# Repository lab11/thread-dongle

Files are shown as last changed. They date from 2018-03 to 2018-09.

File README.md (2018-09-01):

Thread USB Dongle
=================

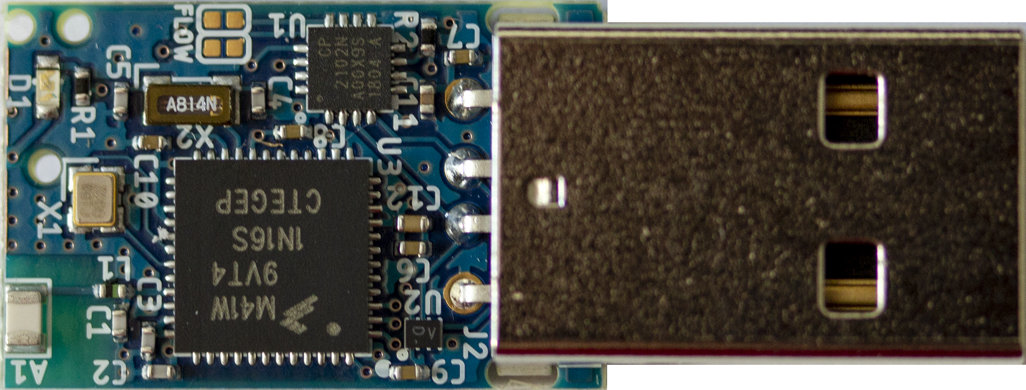
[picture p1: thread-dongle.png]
Thread Dongle


This repo holds the designs for an IEEE 802.15.4 USB dongle that is compatible
with the thread networking stack and supported by [Openthread](https://github.com/openthread/openthread).
The dongle functions as an NCP mode and is compatible with the OpenThread
[Border Router](https://github.com/openthread/borderrouter).

Currently there are no readily available commercial IEEE USB Thread NCP dongles
for a reasonable cost. This dongle is designed to be inexpensive, consists of
only a USB connector, serial to UART converter, and an 802.15.4 radio SoC.

Hardware designs are located in
[hardware](https://github.com/lab11/thread-dongle/tree/master/hardware), and
firmware is located in
[software](https://github.com/lab11/thread-dongle/tree/master/software).
Firmware is based on the OpenThread NCP implementation.

To clone this repo and submodules:
```
git clone --recursive https://github.com/lab11/thread-dongle.git
```

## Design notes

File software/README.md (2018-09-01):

Thread USB Dongle Firmware
==========================

Ensure the OpenThread submodule is initialized and checked out:
```
git submodule init
git submodule update
```

Install required dependencies and build the NCP firmware:
```
./build
```

Flash the firmware with a SEGGER jlink probe:
```
./flash
```

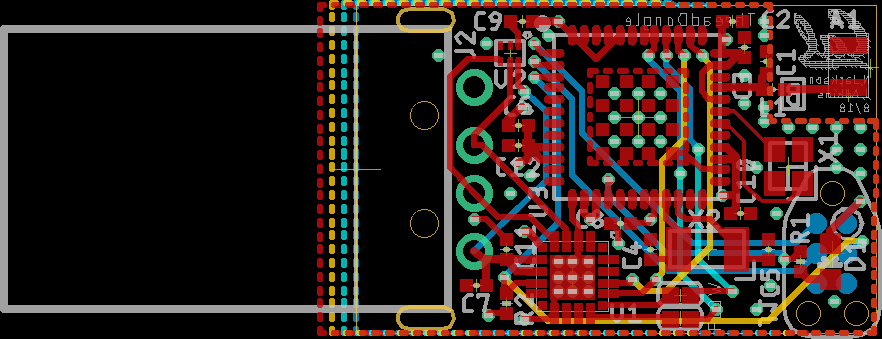
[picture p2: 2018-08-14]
hardware/rev_b/thread_dongle_pcb.png

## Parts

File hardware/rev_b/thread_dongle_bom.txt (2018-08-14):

# Bill of Materials
# Converted from thread_dongle_bom.xlsx
# Generated by bom_to_text.py
#
# # Bill of Materials                                                                                                                                                                                                   
# # Converted from {}                                                                                                                                                                                                   
# # Generated by bom_to_text.py                                                                                                                                                                                         
# #                                                                                                                                                                                                                     
#                                                                                                                                                                                                                       
# thread_dongle                                                                                                                                                                                                         
# Qty                            Value            Device             Package                     Parts                Description                          DIGIKEY                MANUFACTURER  MPN                     Notes
1                                                 AH212M             AH212M                      A1                   Small 2.4Ghz chip antenna            587-2725-1-ND                        AH212M245001-T          
1                                                 INDUCTOR0402       0402_CAP                    L1                   A very specific inductor             490-6573-1-ND                        LQG15HS5N1S02D          
5                                0.1uF            CAPACITOR0402_CAP  0402_CAP                    C6, C7, C8, C9, C10  SMD Capacitor                        587-1227-1-ND                        LMK105BJ104KV-F         Substitute OK
1                                0.7pF            CAPACITOR0402_CAP  0402_CAP                    C1                   SMD Capacitor                        490-6267-1-ND                        GRM1555C1HR70BA01D      Substitute OK
1                                1.0uF            CAPACITOR0402_CAP  0402_CAP                    C11                  SMD Capacitor                        490-10018-1-ND                       GRM155R61E105MA12D      Substitute OK
1                                10k              RESISTOR0402_RES   0402_RES                    R2                   Resistor                             311-10KJRCT-ND                       RC0402JR-0710KL         Substitute OK
4                                12pF             CAPACITOR0402_CAP  0402_CAP                    C2, C3, C4, C5       SMD Capacitor                        490-5924-1-ND                        GRM1555C1H120JA01D      Substitute OK
1                                1k               RESISTOR0402_RES   0402_RES                    R1                   Resistor                             311-1.0KJRCT-ND                      RC0402JR-071KL          Substitute OK
1                                4.7uF            CAPACITOR0402_CAP  0402_CAP                    C12                  SMD Capacitor                        490-5915-1-ND                        GRM155R60J475ME47D      Substitute OK
1                                CP2102N-20       CP2102N-20         QFN-20-3MM                  U1                   A cheap, simple USB to UART adapter  336-3692-ND            SiLabs        CP2102N-A01-GQFN20      
1                                ESDR0502N        ESDR0502N          UDFN-6                      U2                                                        ESDR0502NMUTBGOSCT-ND                ESDR0502NMUTBG          
1                                FA-128           FA-128             FA-128                      X1                   Epson MHz RANGE CRYSTAL UNIT         SER4079CT-ND                         FA-128 32.0000MF20X-K5  
1                                FA-135           FA-135             FC-135                      X2                   Epson kHz RANGE CRYSTAL UNIT         SER4086CT-ND                         FC-135 32.7680KA-AG3    
1                                KW41Z            KW41Z              LAMINATE-QFN-48-7MM         U3                   NXP KW21Z Cortex M0+ 802.15.4        MKW41Z512VHT4-ND                     MKW41Z512VHT4           
1                                LED0603          LED0603            LED-0603                    D1                   LED                                  160-1837-6-ND                        LTST-C194TBKT           
1                                USB-A-MALE-PLUG  USB-A-MALE-PLUG    USB_A_MALE_PLUG_CUI_UP2-AH  J2                   USB A Male plug connector            102-3996-ND            CUI           UP2-AH-1-TH

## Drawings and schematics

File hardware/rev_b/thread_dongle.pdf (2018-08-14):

1 FLOWCONTROL ENABLE | C10, C11, C12 place close to pin 20, 44, 28 C13, C14 place close to pins 36, 35 USB-A-MALE-PLUG | 3v3 GND | GND U² ESDR⁰⁵⁰²N | 0.1uF 4.7uF 0.1uF 1.0uF | GND GND GND | TC2030-JLINK-NL ³v3 GND ¹⁰k | LED⁰⁶⁰³ ³v3 | 1k CP2102N-20 | 0.1uF | 0.1uF | 0.1uF 12pF | 12pF | GND ³v3 GND | FA-128 FA-135 GND | 0.7pF GND ¹²pF | 12pF GND ⁺⁵V | P$1 D- | P$2 D+ | P$3 GND | P$4 J2 | VUSB P$6 D⁺ P$5 D⁻ P$4 GND P$1 | C⁶ C¹² C⁷ C¹¹ | SWDIO SWDCLK SWO RESET | VCC GNDJ1 R² | D¹ R¹ GND D- D+VBUS VREGIN | RST TXD RXD CTS RTS GPIO0/CLK GPIO1/485 WAKEUP SUSPEND SUSPEND VDD GPIO2/TXT GPIO3/RXT U1 | SWD_DIO 1 | SWD_CLK 2 | RESET 3 | PTA16 | 4 PTA17 | 5 PTA18 | 6 PTA19 | 7 PSWITCH 8 | DCDC_CFG 9 | DCDC_LP 11 | DCDC_LN 12 | VDD_1P8_OUT 14 | PTB0 | 16 PTB1 | 17 PTB2 | 18 PTB3 | 19 VDD 10*4 | PTB16/EXTAL32K 21 | PTB17/XTAL32K 22 | PTB18 | 23 ADC0_DP0 | 24 ADC0_DM0 | 25 VREFH | 27 VDDA 28 | XTAL_OUT 29 | EXTAL 30 | XTAL 31 | ANT | 33 VDD_RF 35*2 | PTC1 | 37 PTC2 | 38 PTC3 | 39 PTC4 | 40 PTC5 | 41 PTC6 | 42 PTC7 | 43 PTC17 | 46 PTC18 | 47 PTC19 | 48 GND 13*19 | VDD_1P5/PMC 15 | PTC16 | 45 U3 KW41Z C⁸ | C⁹ | C¹⁰ C² | C³ 1 | 3 X1GND 2 | 1 X2 | L1 C¹ SJ1 SJ2 | C⁴ | C⁵ | RESET RESET RESET | SWDIO | SWDIO CP_RTS CP_RTS | KW21Z_RX KW21Z_RX | KW21Z_TX KW21Z_TX | KW21Z_CTS KW21Z_CTS | KW21Z_RTS KW21Z_RTS | CP_CTS CP_CTS | SWDCLK SWDCLK

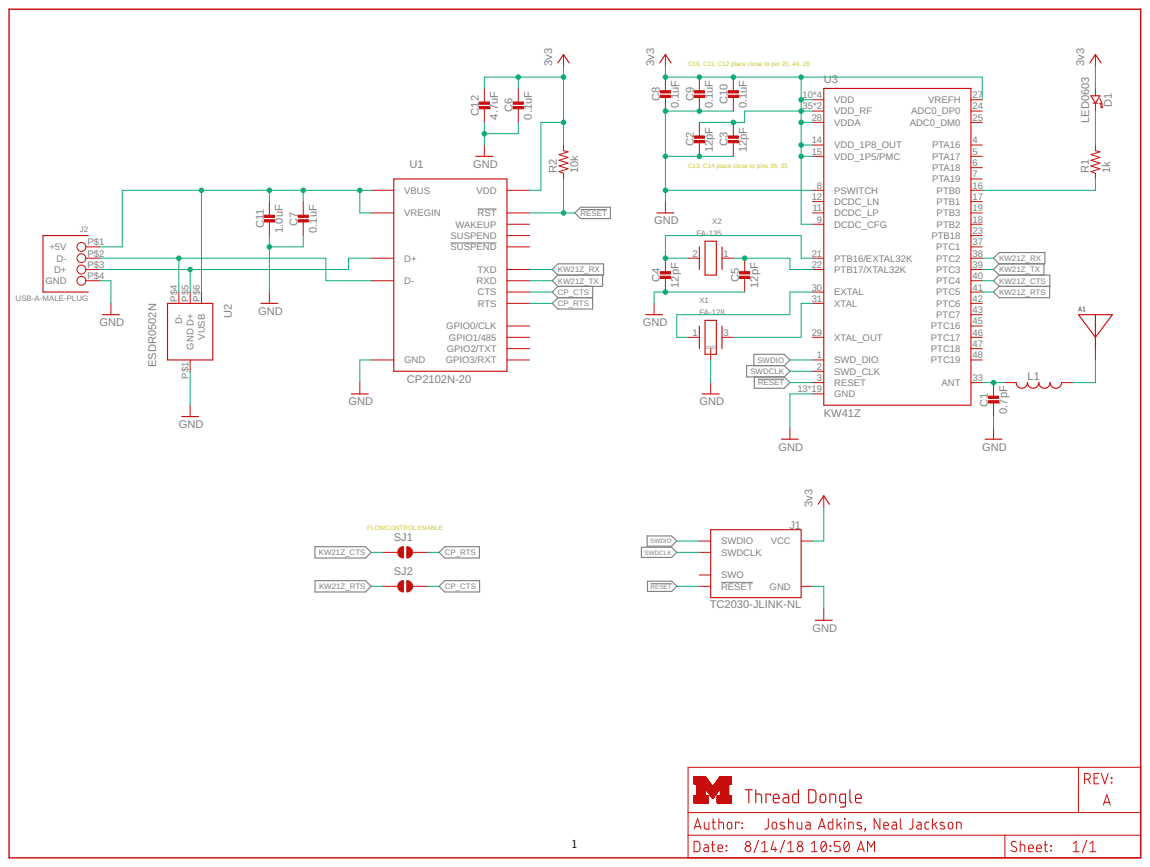
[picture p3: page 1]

## Top and Bottom Layers

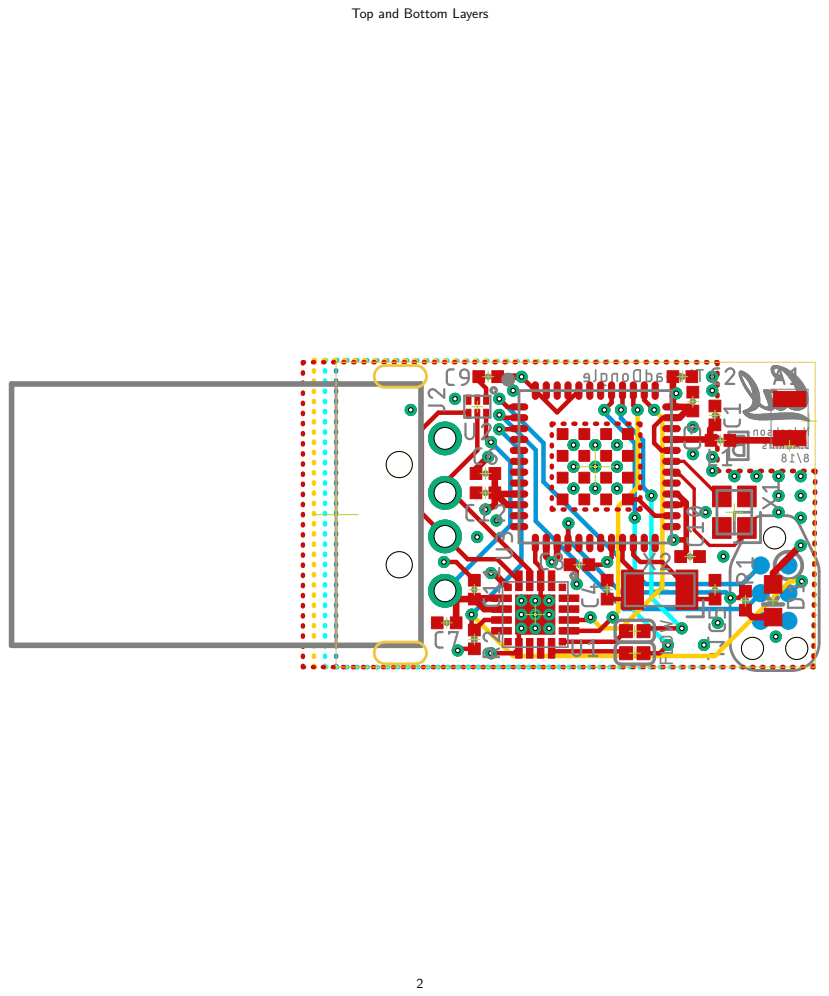
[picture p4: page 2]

## Top Layer

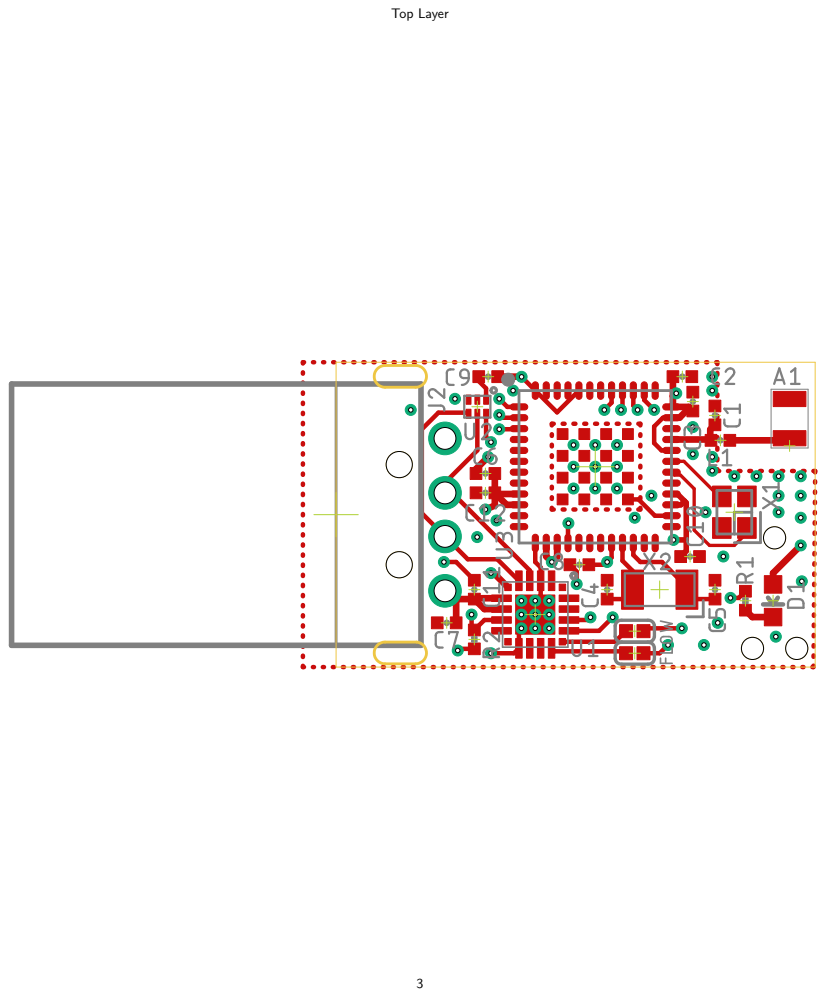
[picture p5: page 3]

## Bottom Layer

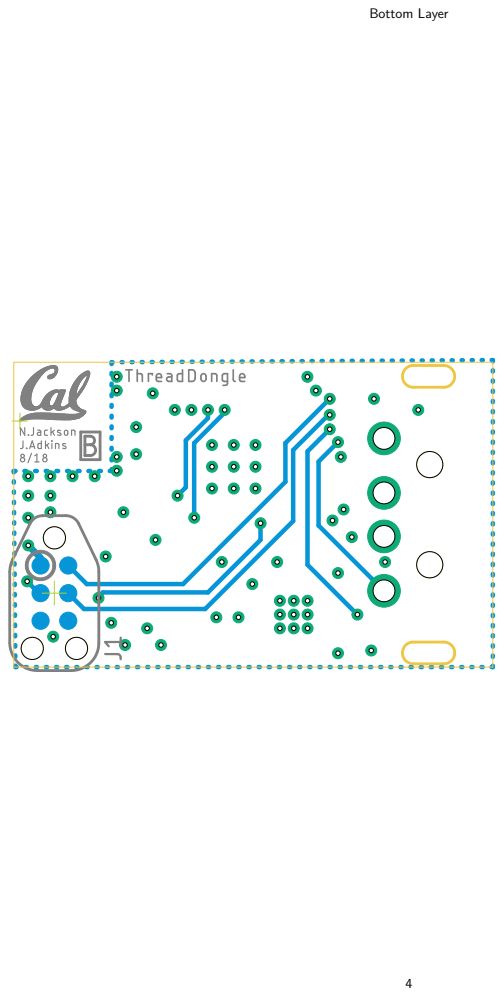
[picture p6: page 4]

## Top Copper Layer

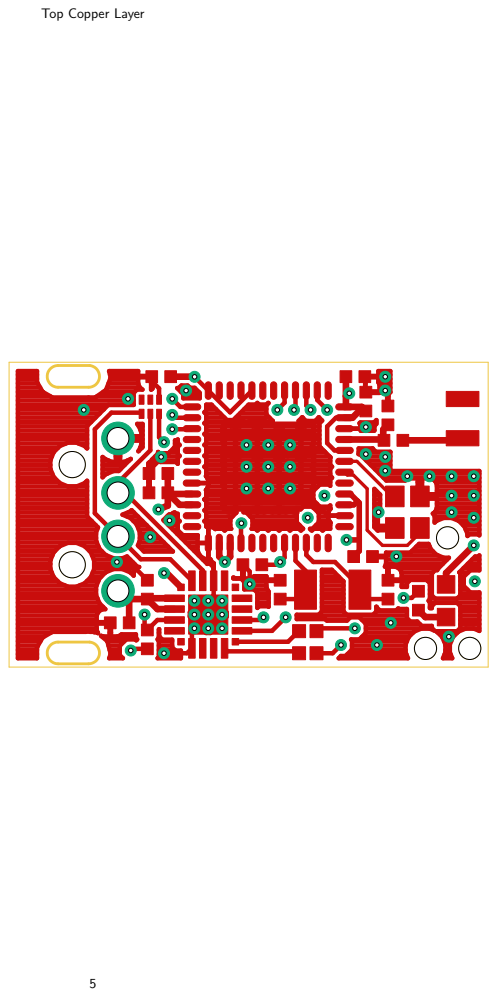
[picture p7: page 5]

## Layer 2 Copper

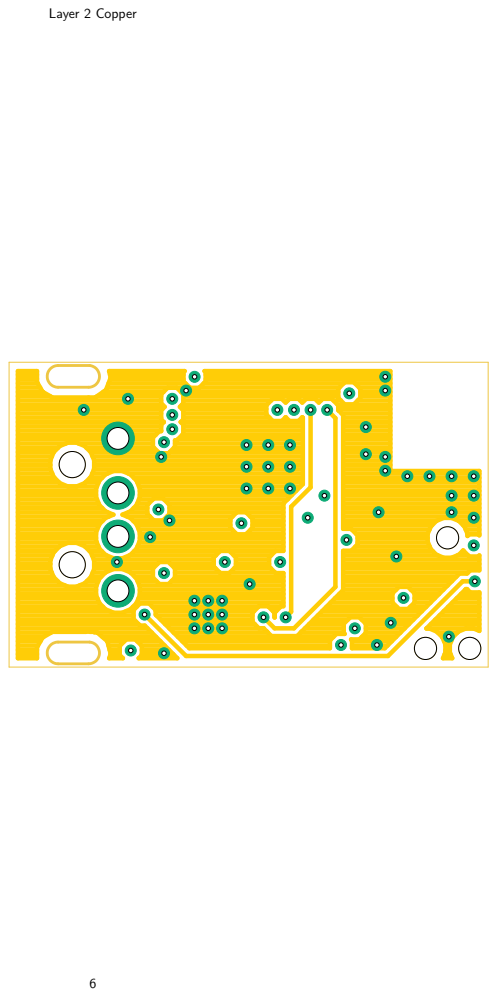
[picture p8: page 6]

## Layer 3 Copper

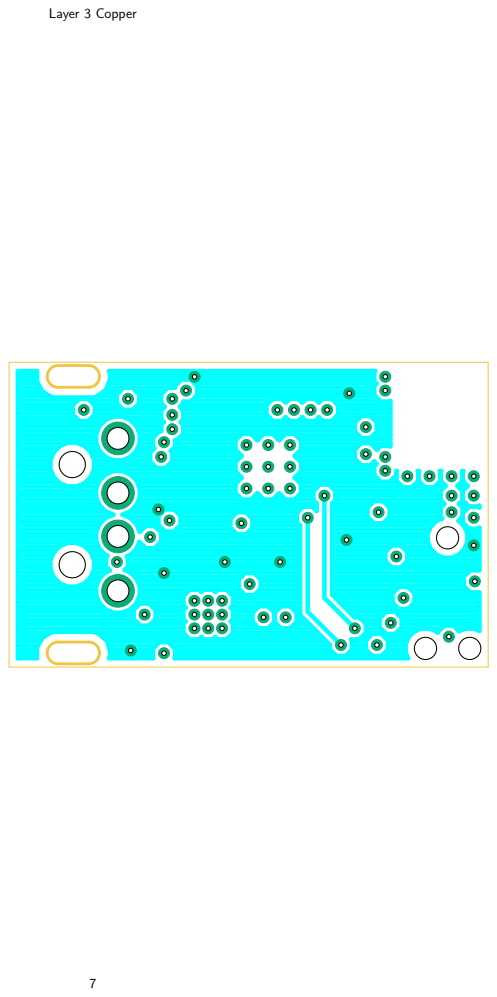
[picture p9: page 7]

## Bottom Copper Layer

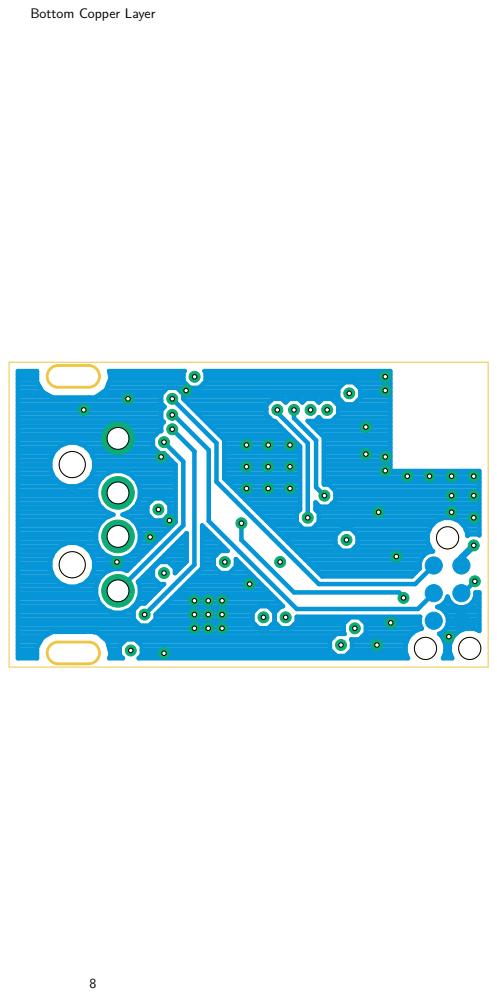
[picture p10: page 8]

## Top Paste Layer with Silkscreen

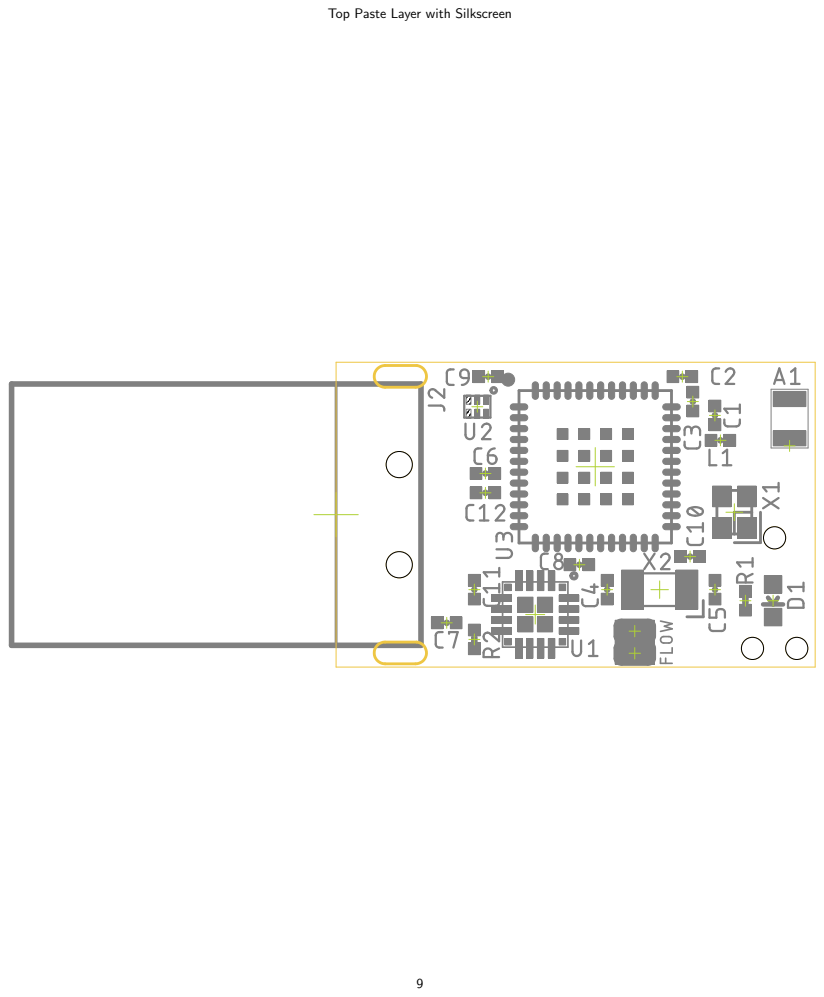
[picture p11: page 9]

## Bottom Paste Layer with Silkscreen

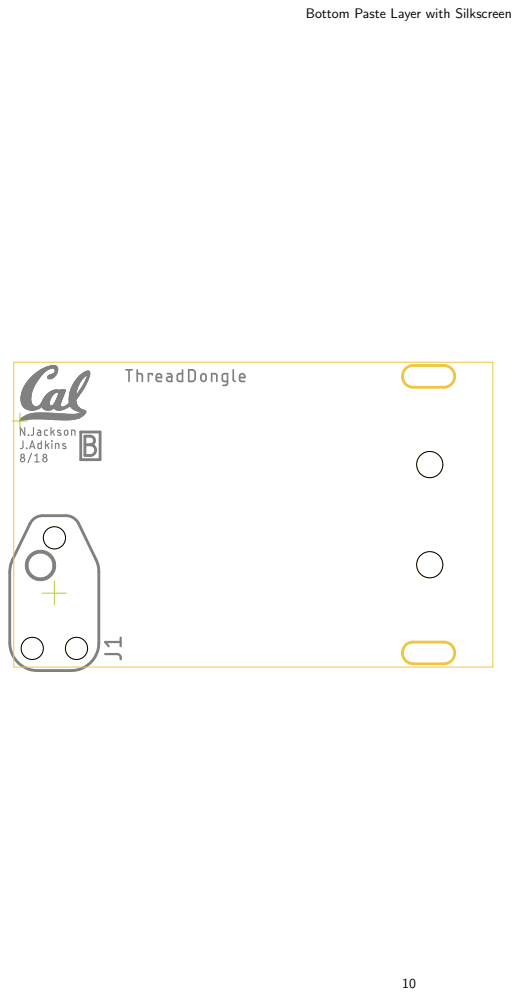
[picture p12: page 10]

## Top and Bottom Layers 1:1 Scale

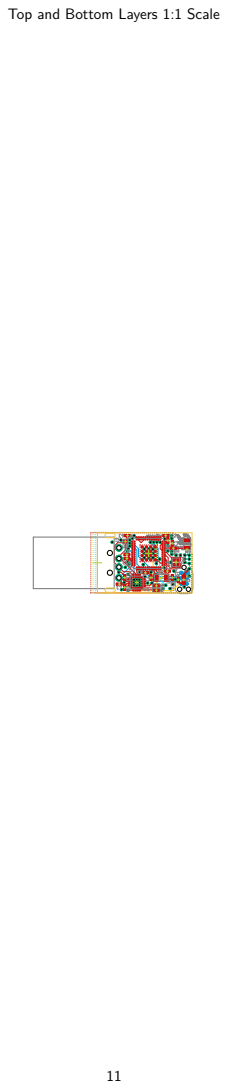
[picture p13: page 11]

## Top Layer 1:1 Scale

## Layer 2 Copper 1:1 Scale

## Layer 3 Copper 1:1 Scale

## Bottom Copper Layer 1:1 Scale

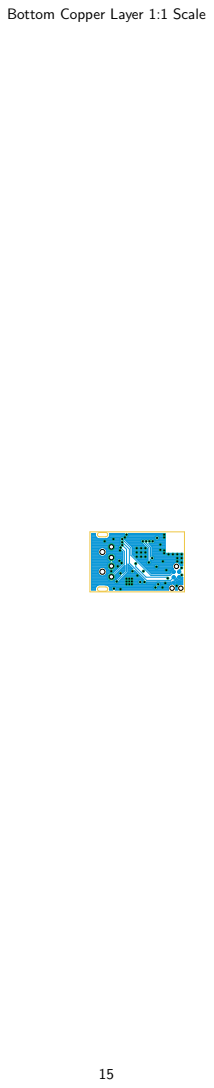
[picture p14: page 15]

16

### thread_dongle

Qty | Value | Device | Package | Parts | Description | DIGIKEY | MANUFACTURER | MPN | Notes
1 | | AH212M | AH212M | A1 | Small 2.4Ghz chip antenna | 587-2725-1-ND | | AH212M245001-T
1 | | INDUCTOR0402 | 0402_CAP | L1 | A very specific inductor | 490-6573-1-ND | | LQG15HS5N1S02D
5 | 0.1uF | CAPACITOR0402_CAP | 0402_CAP | C6, C7, C8, C9, C10 | SMD Capacitor | 587-1227-1-ND | LMK105BJ104KV-F | Substitute OK
1 | 0.7pF | CAPACITOR0402_CAP | 0402_CAP | C1 | SMD Capacitor | 490-6267-1-ND | GRM1555C1HR70BA01D | Substitute OK
1 | 1.0uF | CAPACITOR0402_CAP | 0402_CAP | C11 | SMD Capacitor | 490-10018-1-ND | GRM155R61E105MA12D | Substitute OK
1 | 10k | RESISTOR0402_RES | 0402_RES | R2 | Resistor | 311-10KJRCT-ND | RC0402JR-0710KL | Substitute OK
4 | 12pF | CAPACITOR0402_CAP | 0402_CAP | C2, C3, C4, C5 | SMD Capacitor | 490-5924-1-ND | GRM1555C1H120JA01D | Substitute OK
1 | 1k | RESISTOR0402_RES | 0402_RES | R1 | Resistor | 311-1.0KJRCT-ND | RC0402JR-071KL | Substitute OK
1 | 4.7uF | CAPACITOR0402_CAP | 0402_CAP | C12 | SMD Capacitor | 490-5915-1-ND | GRM155R60J475ME47D | Substitute OK
1 | CP2102N-20 | CP2102N-20 | QFN-20-3MM | U1 | A cheap, simple USB to UART adapter | 336-3692-ND | SiLabs | CP2102N-A01-GQFN20
1 | ESDR0502N | ESDR0502N | UDFN-6 | U2 | | ESDR0502NMUTBGOSCT-ND | | ESDR0502NMUTBG
1 | FA-128 | FA-128 | FA-128 | X1 | Epson MHz RANGE CRYSTAL UNIT | SER4079CT-ND | | FA-128 32.0000MF20X-K5
1 | FA-135 | FA-135 | FC-135 | X2 | Epson kHz RANGE CRYSTAL UNIT | SER4086CT-ND | | FC-135 32.7680KA-AG3
1 | KW41Z | KW41Z | LAMINATE-QFN-48-7MM | U3 | NXP KW21Z Cortex M0+ 802.15.4 | MKW41Z512VHT4-ND | | MKW41Z512VHT4
1 | LED0603 | LED0603 | LED-0603 | D1 | LED | 160-1837-6-ND | | LTST-C194TBKT
1 | USB-A-MALE-PLUG | USB-A-MALE-PLUG | USB_A_MALE_PLUG_CUI_UP2-AH | J2 | USB A Male plug connector | 102-3996-ND | CUI | UP2-AH-1-TH

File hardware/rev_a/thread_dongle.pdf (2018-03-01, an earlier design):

1 FLOWCONTROL ENABLE; C10, C11, C12 place close to pin 20, 44, 28 C13, C14 place close to pins 36, 35 USB-A-MALE-PLUG; 3v3 GND; GND U² ESDR⁰⁵⁰²N; GND GND GND; TC2030-JLINK-NL ³v3 GND ¹⁰k; LED⁰⁶⁰³ ³v3; GND ³v3 GND; FA-128 FA-135 GND; 0.7pF GND ¹²pF; 12pF GND ⁺⁵V; P$3 GND; VUSB P$6 D⁺ P$5 D⁻ P$4 GND P$1; C⁶ C¹² C⁷ C¹¹; SWDIO SWDCLK SWO RESET; VCC GNDJ1 R²; D¹ R¹ GND D- D+VBUS VREGIN; RST TXD RXD CTS RTS GPIO0/CLK GPIO1/485 WAKEUP SUSPEND SUSPEND VDD GPIO2/TXT GPIO3/RXT U1; SWD_DIO 1; SWD_CLK 2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

### Top and Bottom Layers


### Top Layer


### Bottom Layer


### Top Copper Layer


### Layer 2 Copper


### Layer 3 Copper


### Bottom Copper Layer


### Top Paste Layer with Silkscreen


### Bottom Paste Layer with Silkscreen


### Top and Bottom Layers 1:1 Scale


### Top Layer 1:1 Scale

### Layer 2 Copper 1:1 Scale

### Layer 3 Copper 1:1 Scale

### Bottom Copper Layer 1:1 Scale


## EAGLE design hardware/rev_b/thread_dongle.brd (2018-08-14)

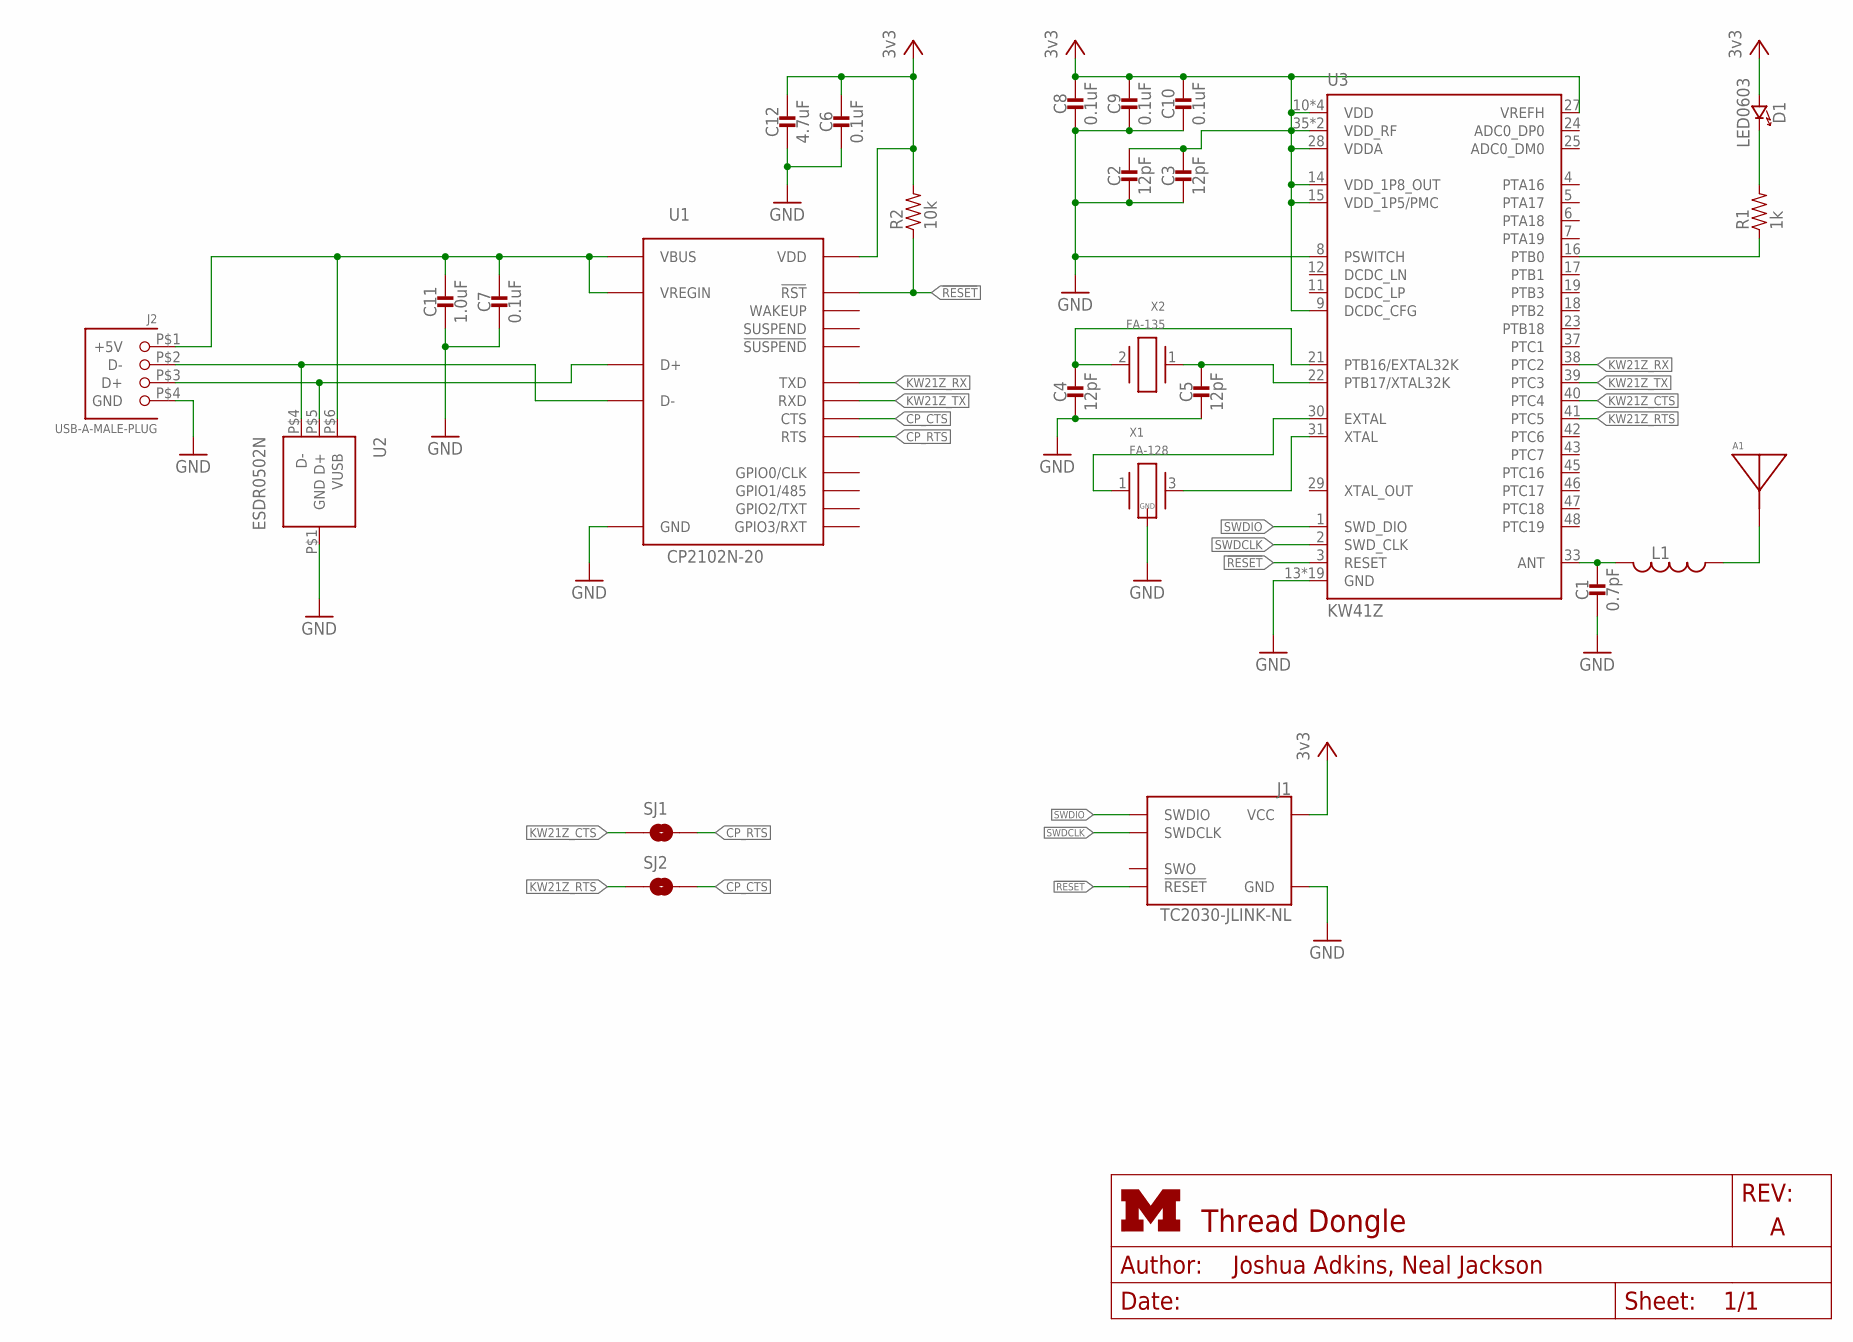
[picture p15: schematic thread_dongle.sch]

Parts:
A1: AH212M
C1: 0.7pF; 0402_CAP; MPN GRM1555C1HR70BA01D; DIGIKEY 490-6267-1-ND
C2, C3, C4, C5: 12pF; 0402_CAP; MPN GRM1555C1H120JA01D; DIGIKEY 490-5924-1-ND
C6, C7, C8, C9, C10: 0.1uF; 0402_CAP; MPN LMK105BJ104KV-F; DIGIKEY 587-1227-1-ND
C11: 1.0uF; 0402_CAP; MPN GRM155R61E105MA12D; DIGIKEY 490-10018-1-ND
C12: 4.7uF; 0402_CAP; MPN GRM155R60J475ME47D; DIGIKEY 490-5915-1-ND
D1: LED0603; LED-0603; MPN LTST-C194TBKT; DIGIKEY 160-1837-6-ND
J1: TC2030-JLINK-NL; TC2030-IDC-NL
J2: USB-A-MALE-PLUG; USB_A_MALE_PLUG_CUI_UP2-AH
L1: INDUCTOR0402; 0402_CAP; MPN LQG15HS5N1S02D; DIGIKEY 490-6573-1-ND
R1: 1k; 0402_RES; MPN RC0402JR-071KL; DIGIKEY 311-1.0KJRCT-ND
R2: 10k; 0402_RES; MPN RC0402JR-0710KL; DIGIKEY 311-10KJRCT-ND
SJ1, SJ2: SOLDERJUMPERNC; SJ_2S_SMALL
U1: CP2102N-20; QFN-20-3MM
U2: ESDR0502N; UDFN-6
U3: KW41Z; LAMINATE-QFN-48-7MM
X1: FA-128; MPN FA-128 32.0000MF20X-K5; DIGIKEY SER4079CT-ND
X2: FA-135; FC-135; MPN FC-135 32.7680KA-AG3; DIGIKEY SER4086CT-ND

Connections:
5V: C7.1, C11.1, J2.P$1 (+5V), U1.7 (VREGIN), U1.8 (VBUS), U2.P$6 (VUSB)
!RESET: J1.3 (!RESET), R2.1, U1.9 (!RST), U3.3 (RESET)
CP_CTS: SJ2.2, U1.15 (CTS)
CP_RTS: SJ1.2, U1.16 (RTS)
D+: J2.P$3 (D+), U1.4 (D+), U2.P$5 (D+)
D-: J2.P$2 (D-), U1.5 (D-), U2.P$4 (D-)
GND: C1.2, C2.2, C3.2, C4.2, C5.2, C6.2, C7.2, C8.2, C9.2, C10.2, C11.2, C12.2, J1.5 (GND), J2.P$4 (GND), U1.3 (GND), U1.12 (GND), U1.P$1 (GND), U2.P$1 (GND), U3.8 (PSWITCH), U3.13 (GND), U3.26 (GND), U3.34 (GND), U3.49 (GND), U3.50 (GND), U3.51 (GND), U3.52 (GND), U3.53 (GND), U3.54 (GND), U3.55 (GND), U3.56 (GND), U3.57 (GND), U3.58 (GND), U3.59 (GND), U3.60 (GND), U3.61 (GND), U3.62 (GND), U3.63 (GND), U3.64 (GND), X1.2 (GND), X1.4 (GND)
KW21Z_CTS: SJ1.1, U3.40 (PTC4)
KW21Z_RTS: SJ2.1, U3.41 (PTC5)
KW21Z_RX: U1.18 (TXD), U3.38 (PTC2)
KW21Z_TX: U1.17 (RXD), U3.39 (PTC3)
unnamed: C4.1, U3.21 (PTB16/EXTAL32K), X2.2
unnamed: C5.1, U3.22 (PTB17/XTAL32K), X2.1
unnamed: U3.31 (XTAL), X1.3 (2)
unnamed: D1.C (CATHODE), R1.2
unnamed: R1.1, U3.16 (PTB0)
unnamed: U3.30 (EXTAL), X1.1
unnamed: C1.1, L1.2, U3.33 (ANT)
unnamed: A1.P1, L1.1
SWDCLK: J1.4 (SWDCLK), U3.2 (SWD_CLK)
SWDIO: J1.2 (SWDIO), U3.1 (SWD_DIO)
VCC: C2.1, C3.1, C6.1, C8.1, C9.1, C10.1, C12.1, D1.A (ANODE), J1.1 (VCC), R2.2, U1.6 (VDD), U3.9 (DCDC_CFG), U3.10 (VDD), U3.14 (VDD_1P8_OUT), U3.15 (VDD_1P5/PMC), U3.20 (VDD), U3.27 (VREFH), U3.28 (VDDA), U3.32 (VDD), U3.35 (VDD_RF), U3.36 (VDD_RF), U3.44 (VDD)

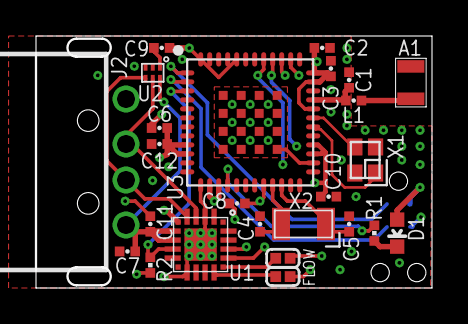
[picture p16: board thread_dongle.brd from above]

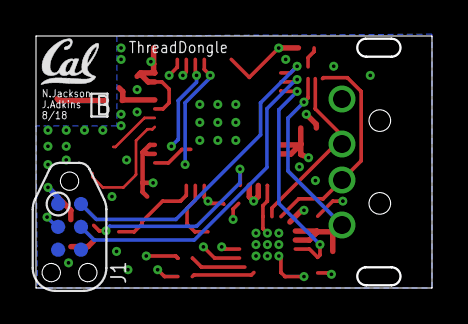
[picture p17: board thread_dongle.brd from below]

Board: 4 copper layers, 22.0 x 14.0 mm, 27 parts (2 on the bottom side), 22 nets.

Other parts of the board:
U$1: UCB_CAL_100MIL

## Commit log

2017-12-16 add some parts on schematic
    [thread_dongle.sch]
2017-12-17 added routed board and schematic
    [thread_dongle.brd, thread_dongle.sch]
2017-12-18 smaller board, cheaper uart bridge
    [thread_dongle.brd, thread_dongle.sch]
2018-01-31 Update with KW21Z instead of SAMR21
    [thread_dongle.brd, thread_dongle.sch]
2018-02-02 Nothing to do and no errors
    [thread_dongle.brd, thread_dongle.sch]
2018-02-05 Fix up silkscreen
    [thread_dongle.brd, thread_dongle.sch]
2018-03-01 ship it
    [thread_dongle.brd, thread_dongle.sch, thread_dongle_bom.csv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]
2018-08-14 Rev b
    Switch to 41z, because it works
    Add pin 1 indicator for usb/uart bridge
    [thread_dongle.brd, thread_dongle.sch, thread_dongle_bom.csv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]
